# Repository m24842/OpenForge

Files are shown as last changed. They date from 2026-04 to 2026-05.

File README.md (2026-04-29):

<p align="center">
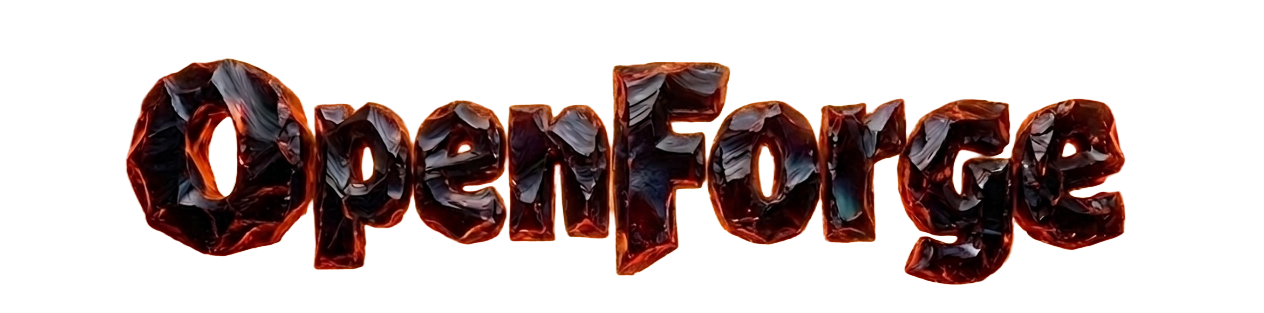
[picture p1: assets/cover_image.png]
  
</p>
<h3 align="center">GT Senior Design Project Spring 2026</h3>
<h4 align="center">
  <a href="https://coe.gatech.edu/news/2026/04/protecting-organs-water-and-military-earn-top-honors-capstone-expo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">Honorable Mention</a>
</h4>

## Overview
OpenForge is an open-source, low-cost, hobbyist-level induction furnace created to reduce the cost barrier to entry for metalworking and rapid prototyping.

<p align="center">
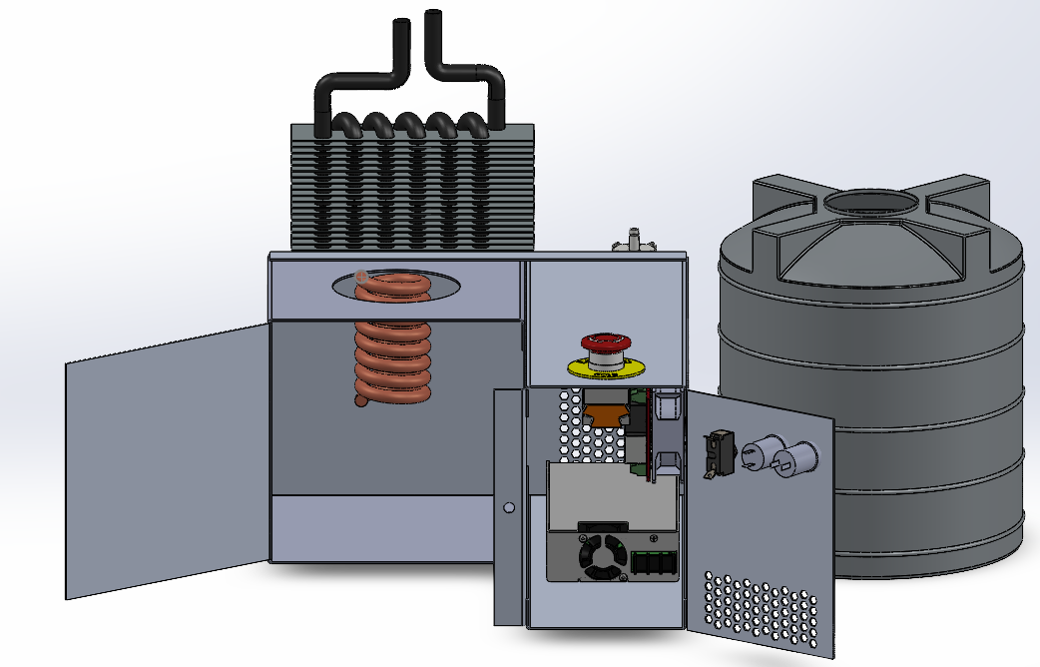
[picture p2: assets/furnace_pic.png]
  
</p>

## Documentation
### [Guides](docs/guides/README.md)
  1. [Setup](docs/guides/setup.md)
  2. [Usage](docs/guides/usage.md)
  3. [Develop](docs/guides/dev.md)
  4. [Debug](docs/guides/debug.md)

### [Reference](docs/reference/README.md)
  * [Architecture](docs/reference/arch.md)
  * [Configuration](docs/reference/configs.md)

## Demo Video
<p align="center">
  <a href="https://www.youtube.com/watch?v=rfKfzx6W2i8">
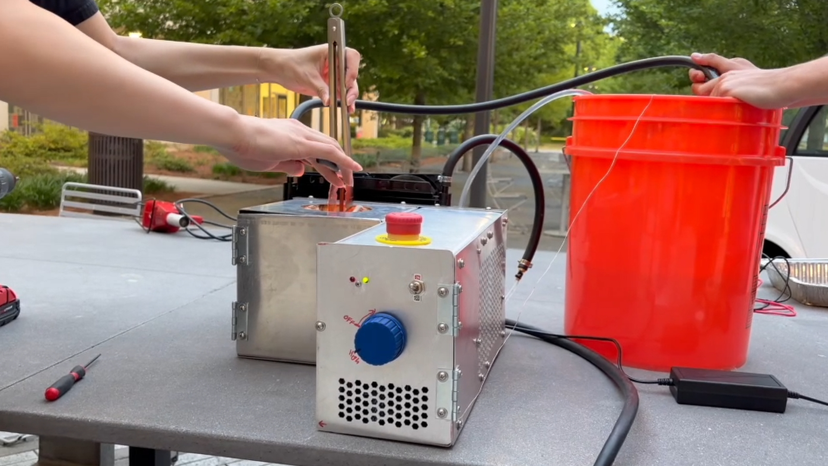
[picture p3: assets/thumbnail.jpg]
OpenForge Demo
    
  </a>
</p>

## The Team
| | Profile | Major |
| :--: | :---: | :----: |
|  | [@m24842](https://github.com/m24842) | EE |
|  | [@mollyg27](https://github.com/mollyg27) | ME |
|  | [@Dmay37](https://github.com/Dmay37) | EE |
|  | [@14joragu](https://github.com/14joragu) | EE |
|  | [@61olihar](https://github.com/61olihar) | ME |
|  | [@gchen368](https://github.gatech.edu/gchen368) | CE |

## Acknowledgments
Special thanks to __Dr. Lukas Graber__ and __Dr. Peter Hesketh__ for their guidance, insight, and support throughout this project.

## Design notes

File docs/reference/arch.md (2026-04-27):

# Architecture

## Overview

<p align="center">
  OpenForge
</p>

* [User Interface](#user-interface)
* [Heating](#heating)
* [Cooling](#cooling)
* [Control](#control)

## User Interface

### Components
|Name|Suggested Part|
|:---|---:|
|Toggle switch|[Amazon link](https://a.co/d/08M4XrNV)|
|Rotary potentiometer 10kΩ (power dial)|[Amazon link](https://a.co/d/00b6DRkQ)|
|Emergency stop button|[Amazon link](https://a.co/d/0hutAWxC)|
|120V relay|[Amazon link](https://a.co/d/00kgoHyW)|
|Red LED|-|
|Green LED|-|

### Functionality
__Inputs__:
* User input
* [Control state](#control)

__Outputs__:
* ZVS enable/disable signal
* Power dial position
* LED control signals

The furnace user interface enables intuitive control of the crucible temperature and includes three main inputs: a __power dial__, __enable/disable switch__, and __e-stop button__.

The __power dial__ outputs an analog signal [0V, 3.3V] which is converted to a current limit percentage for the ZVS power supply by the microcontroller. Since the minimum current limiting for the ZVS power supply is 10% rather than 0%, the __enable/disable switch__ allows the output to be shut off completely and enter idle mode. Both setting the current limit and output enable/disable are accomplished using CAN commands supported by the ZVS power supply (see [zvs.py](../../src/zvs.py) for further details and references).

The __e-stop button__ allows immediate termination of ZVS operation by directly controlling a relay to cut off AC power to the ZVS power supply (i.e. bypassing the microcontroller).

The furnace operation mode is displayed using __red and green LEDs__. Each LED is driven independently by the microcontroller, allowing multiple states to be displayed using flash patterns. The four furnace states include:
1. Idle: ⚫️⚫️ (both off)
    * Furnace heating is disabled
2. Ramp: ⚫️🟢 (green on)
    * Furnace is enabled and temperature is __ramping__. Ramping is identified as a changing voltage/current being drawn by the ZVS driver.
3. Steady: ⚫️🟢 (green flashing)
    * Furnace is enabled and temperature is __steady__.
    Steadiness is identified as a roughly constant voltage/current being drawn by the ZVS driver.
4. Overload: 🔴⚫️ (red flashing)
    * Furnace power supply is __overloaded__. The power supply will throttle power unless the temperature setting is reduced (throttling reduces effective power significantly). This generally only occurs when running the furnace on 240VAC.
5. Error: 🔴⚫️ (red on)
    * Furnace has entered an erroneous state. The system controller monitors temperatures of critical components and disables heating if temperature limits are exceeded.

## Heating

### Components
|Name|Suggested Part|
|:---|---:|
|ZVS driver|[Amazon link](https://a.co/d/0dc9iLwj)|
|3kW DC power supply (ZVS power supply)|*included w/ ZVS driver|
|Induction coil|*included w/ ZVS driver|
|IC temperature sensor|[Digikey link](https://www.digikey.com/short/981h0vrd)|
|Bottom pour crucible|[Amazon link](https://a.co/d/0bnduDAu) *hole must be drilled|
|Bottom pour crucible plug|[Amazon link](https://a.co/d/034yB7Kj)|
|Ceramic fiber insulation|[Amazon link](https://a.co/d/070G24vb)|
|Fiber glass coil sheath|[Amazon link](https://a.co/d/0huBojl4)|

### Functionality
__Inputs__:
* [ZVS enable/disable CAN command](#control)
* [ZVS power supply current limit](#control)

__Outputs__:
* Induction coil power
* ZVS temperature
* ZVS power supply temperature
* ZVS power supply output voltage/current

Induction heating is accomplished using a __ZVS driver__. A __3kW power supply__ feeds the __ZVS driver__ to attain temperatures required for melting common engineering metals such as aluminum. The __induction coil__ is water cooled to enable long run times and optimal heating efficiency (see [Cooling](#cooling) for further details).

The __ZVS power supply__ supports CAN commands for adjusting operation parameters such as output voltage, current, fan speed, etc. (see [zvs.py](../../src/zvs.py) for further details and references). Only two parameters are dynamically controlled during furnace operation: _current limit_ and _output enable/disable_. These are transmitted from the microcontroller to the __ZVS power supply__ based on user inputs as discussed in [User Interface](#user-interface).

Additionally, the __ZVS power supply__ supports CAN commands for reading operation parameters. The most relevant values include output voltage, current, and temperature. These are used by the microcontroller to determine furnace operation modes and error conditions as discussed in [User Interface](#user-interface).

## Cooling

### Components
|Name|Suggested Part|
|:---|---:|
|12V fans|[Amazon link](https://a.co/d/06POpfxe)|
|12V pump|*included w/ ZVS driver|
|12V relay|[Amazon link](https://a.co/d/09bBEAkq)|
|12V power supply|[Amazon link](https://a.co/d/0fyLhfdB)|
|Radiator|[Amazon link](https://a.co/d/0breF2rm)|
|Thermocouple + amplifier|[Amazon link](https://a.co/d/0a98Mzv3)|
|Tubing|[Amazon link](https://a.co/d/06ERqqzK)|
|Hose clamps|-|
|Hose adapters|-|
|Reservoir|-|

### Functionality
__Inputs__:
* [Fans on/off signal](#control)

__Outputs__:
* Coolant temperature
* Coolant flow to induction coil

Cooling critical components of the furnace is accomplished using both air and water cooling. Specifically, the induction coil is water cooled while the electronics housing is air cooled. Additionally, __fans__ are installed on the coolant radiator to maintain a reasonable water temperature for circulating through the induction coil.

The __water pump__ is always running to allow for accurate measurements of nominal water temperature using a downstream thermocouple. Water temperature measurements are transmitted to the microcontroller for determining error conditions as discussed in [User Interface](#user-interface). On the other hand, __fans__ are controlled by the microcontroller through a relay. __Fans__ only run while heating is enabled or some temperature limit has been exceeded.

## Control

### Components
|Name|Suggested Part|
|:---|---:|
|Microcontroller (MCU)|[Adafruit link](https://www.adafruit.com/product/5724)|
|CAN transceiver|*onboard the MCU|
|Buck converter|[Amazon link](https://a.co/d/0ix6y9vt)|

### Functionality
__Inputs__:
* [ZVS temperature](#heating)
* [ZVS power supply temperature](#heating)
* [ZVS power supply output voltage/current](#heating)
* [Coolant temperature](#cooling)
* [ZVS enable/disable signal](#user-interface)
* [Power dial position](#user-interface)

__Outputs__:
* Fans on/off signal
* Control state
* ZVS enable/disable CAN command
* ZVS power supply current limit

System control is split into two components: __heating control__ and __cooling control__.

__Heating control__ involves setting the ZVS power supply current limit and output disable/enable based on user inputs and component temperature readings. ZVS power supply parameters directly match user inputs as long as no temperature limits have been exceeded. If an erroneous state is encountered, heating is disabled until the furnace returns to a valid state.

__Cooling control__ involves enabling/disabling the fans for the electronics and coolant radiator. Fans are only enabled while heating is enabled or some temperature limit has been exceeded.

Additionally, the system controller is responsible for updating the furnace state displayed by the [User Interface](#user-interface).

## Miscellaneous

### Components
|Name|Suggested Part|
|:---|---:|
|Aluminum sheet|[link](https://www.onlinemetals.com/en/buy/aluminum/0-063-aluminum-sheet-5052-h32/pid/7128) *24" X 48"|
|Door hinges|-|
|Fasteners|-|

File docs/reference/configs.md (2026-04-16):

# Configuration

> __Note__: All configurations are located in [configs.py](../../src/configs.py). Default values are provided.

> __Note__: Pinouts (and other details) for the RP2040 CAN Bus Feather can be found [here](https://learn.adafruit.com/adafruit-rp2040-can-bus-feather/pinouts).

## User Interface Configurations
* `GREEN_LED_PIN`, `RED_LED_PIN`: Any two GPIO pins can be used
* `DIAL_PIN`: Any ADC capable GPIO pin can be used (i.e. GPIO 26-29)
* `SWITCH_PIN`: Any GPIO pin can be used
* `DIAL_ALPHA`: Determines the smoothing factor for translating dial position to heating power. Values closer to 1.0 reduce smoothing while values closer 0.0 increase smoothing.
* `STEADY_STATE_THRESH`: Determines the maximum deviations in output voltage and current to still be considered steady state. Makes no impact to the heating process, only status visualization.

## ZVS Driver Configurations
* `CAN_SPI`: This should not be changed from 1 since the RP2040 CAN Bus Feather has its CAN transceiver connected to SPI1
* `CAN_SPI_SCK`: Any SCK1 capable GPIO pin can be used (i.e. GPIO 10, 14, or 26)
* `CAN_SPI_MOSI`: Any TX1 capable GPIO pin can be used (i.e. GPIO 11, 15, or 27)
* `CAN_SPI_MISO`: Any RX1 capable GPIO pin can be used (i.e. GPIO 8, 12, or 28)
* `CAN_CS`: This should not be changed from GPIO 19 since CAN_CS is tied to it
* `ZVS_TEMP_PIN`: Any ADC capable GPIO pin can be used (i.e. GPIO 26-29)

## Cooling Configurations
* `COOLING_RELAY_PIN`: Any GPIO pin can be used
* `COOLING_TEMP_SPI`: This should not be changed from 0 since SPI1 is being used for CAN
* `COOLING_TEMP_SCK`: Any SCK0 capable GPIO pin can be used (i.e. GPIO 2 or 6)
* `COOLING_TEMP_MISO`: Any RX0 capable GPIO pin can be used (i.e. GPIO 0 or 4)
* `COOLING_TEMP_CS`: Any CSn0 capable GPIO pin can be used (i.e. GPIO 1 or 5)

## Control Configurations
* `MAX_ZVS_TEMP`: In celsius, determines a condition for which the system cuts power to the ZVS driver
* `MAX_ZVS_PSU_TEMP`: In celsius, determines a condition for which the system cuts power to the ZVS driver
* `MAX_COOLANT_TEMP`: In celsius, determines a condition for which the system cuts power to the ZVS driver

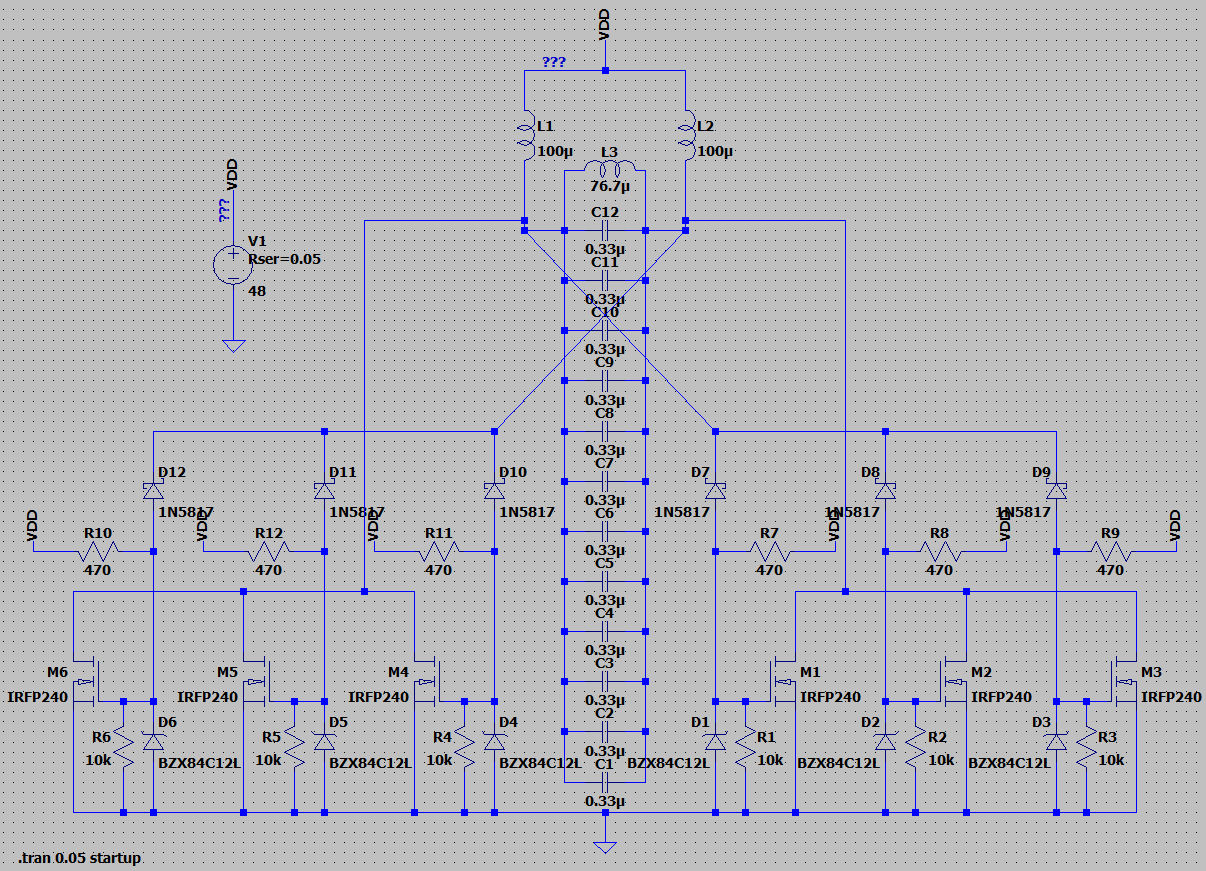
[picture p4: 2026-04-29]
pcb/ZVS_Schematic.png

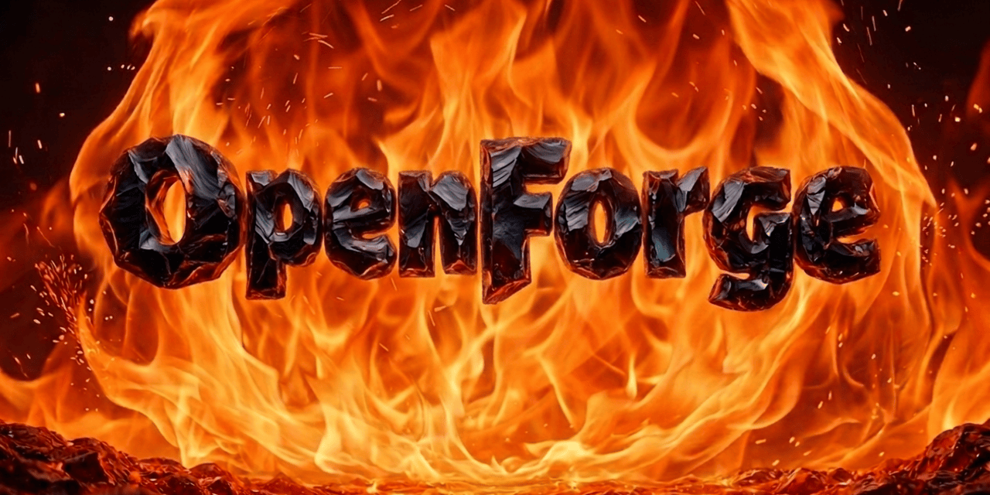
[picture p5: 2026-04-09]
assets/social_preview.png

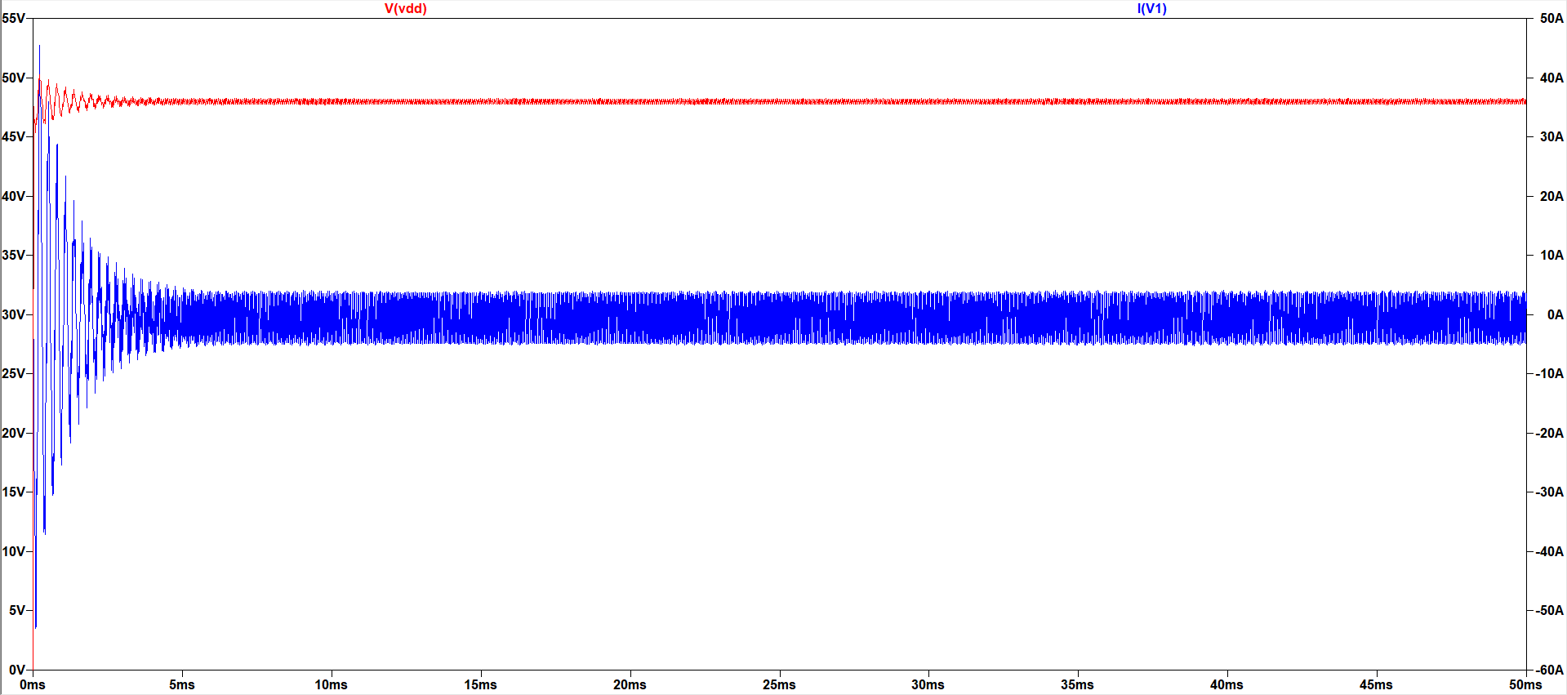
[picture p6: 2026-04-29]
pcb/ZVS_Input_V&I_Waveforms.png

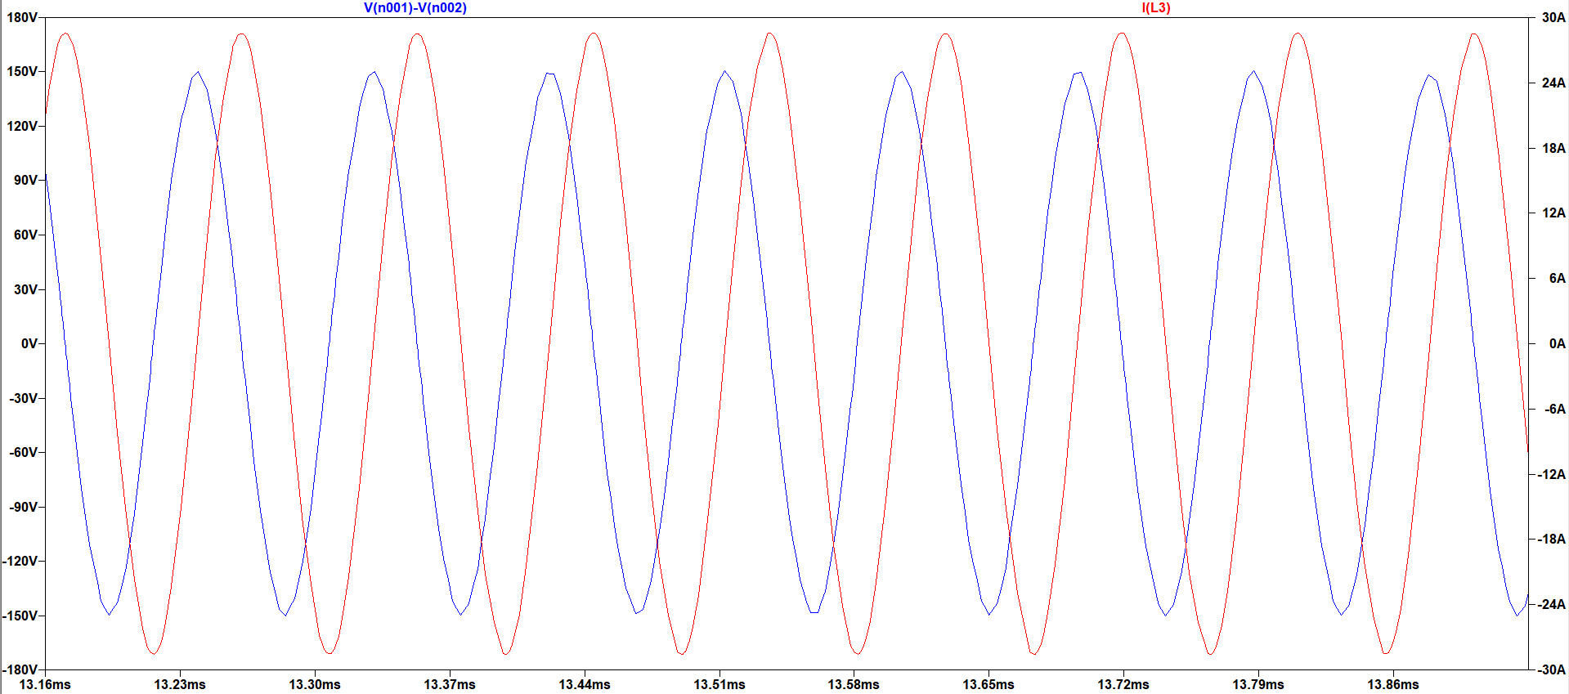
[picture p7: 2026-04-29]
pcb/ZVS_LC_Oscillation_V&I_Waveforms.png

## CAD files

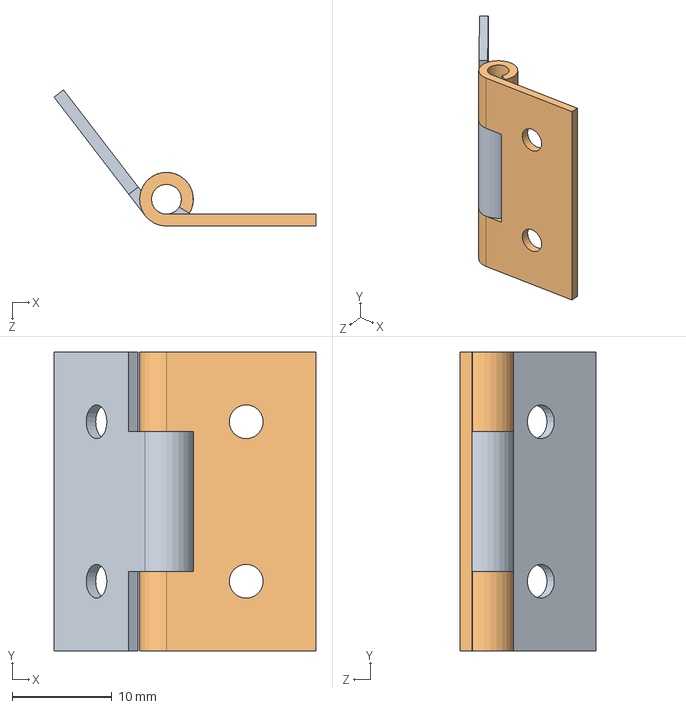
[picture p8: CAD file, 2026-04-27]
cad/PYM_303012_hinge.SLDASM
26.3 x 30.0 x 13.7 mm
PYM_303012_hinge1
PYM_303012_hinge2

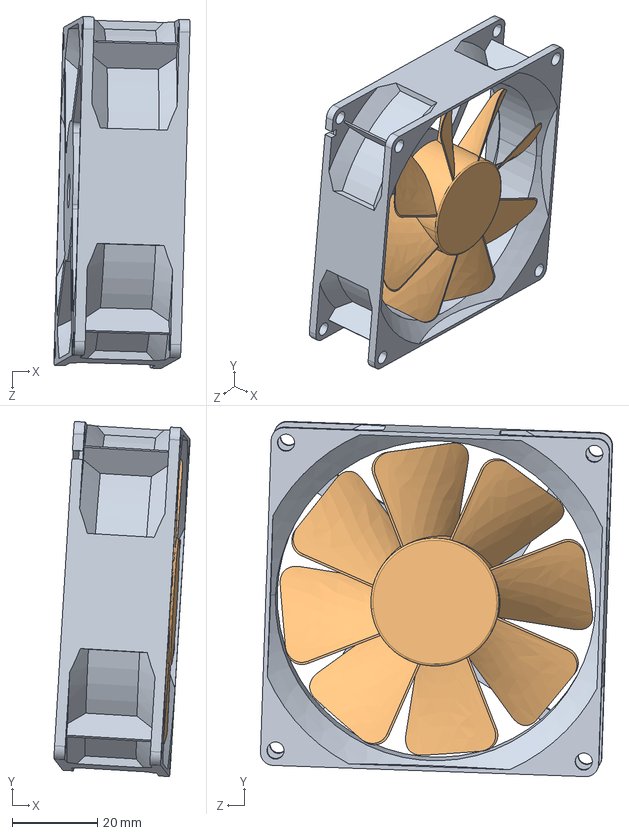
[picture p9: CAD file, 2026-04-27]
cad/Cooling Fan.STEP
31.8 x 83.1 x 82.4 mm
Fan case
Exhaust Fan Propeller

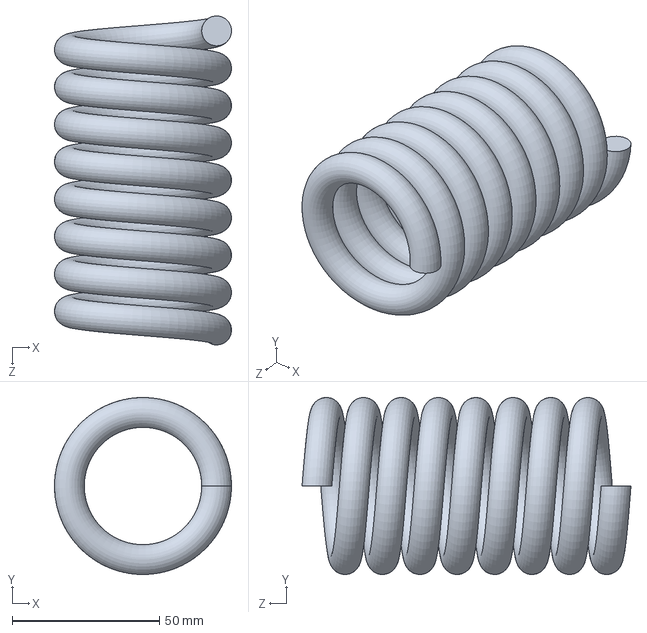
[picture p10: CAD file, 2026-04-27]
cad/coil3.SLDPRT
60.1 x 60.1 x 111.7 mm

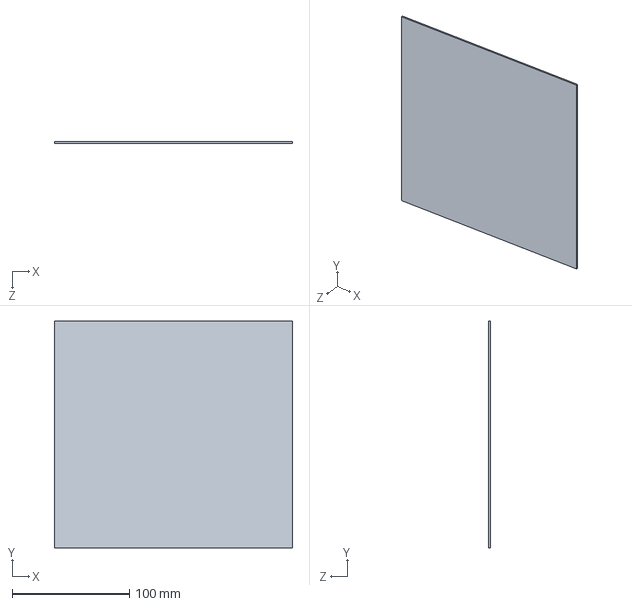
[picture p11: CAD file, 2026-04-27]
cad/door.SLDPRT
203.2 x 193.8 x 1.59 mm

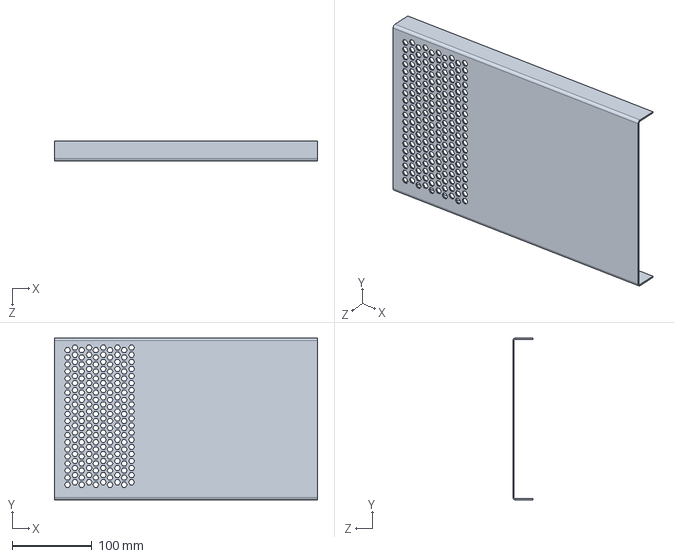
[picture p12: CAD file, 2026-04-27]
cad/back.SLDPRT
330.2 x 203.2 x 25.4 mm

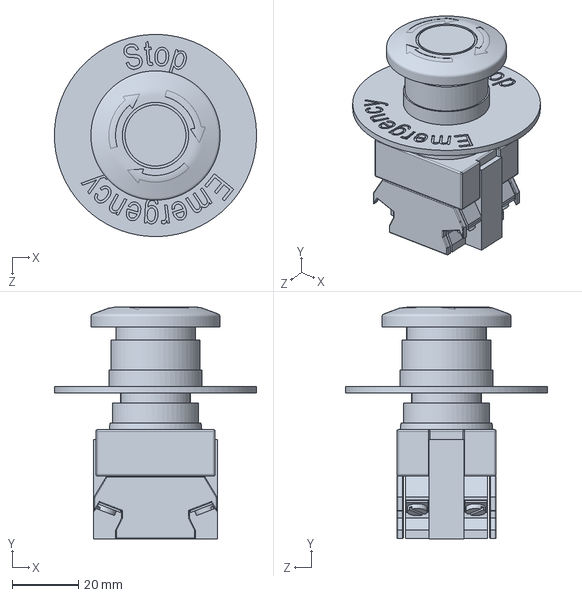
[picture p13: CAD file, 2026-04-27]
cad/Emergency Stop Button.SLDPRT
61.0 x 70.0 x 61.0 mm

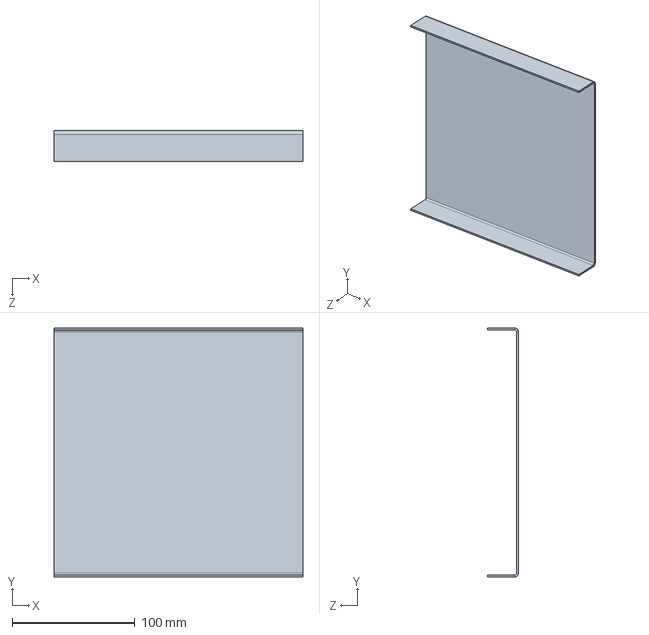
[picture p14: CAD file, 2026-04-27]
cad/bottom.SLDPRT
203.2 x 203.2 x 25.4 mm

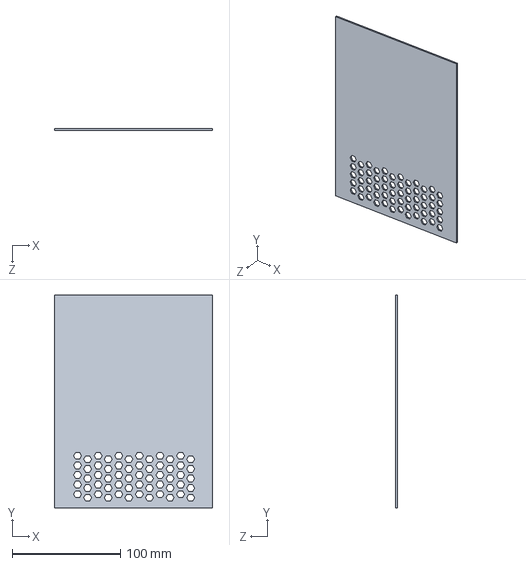
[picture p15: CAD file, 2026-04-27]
cad/controls_panel.SLDPRT
146.1 x 196.9 x 1.59 mm

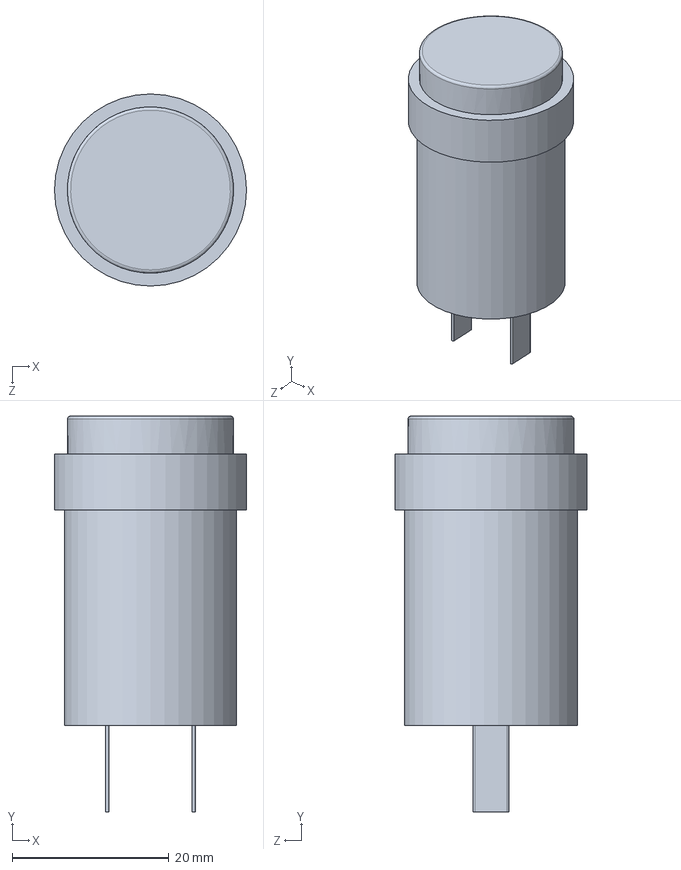
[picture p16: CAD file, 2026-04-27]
cad/LED Status -red.SLDPRT
24.5 x 50.5 x 24.5 mm

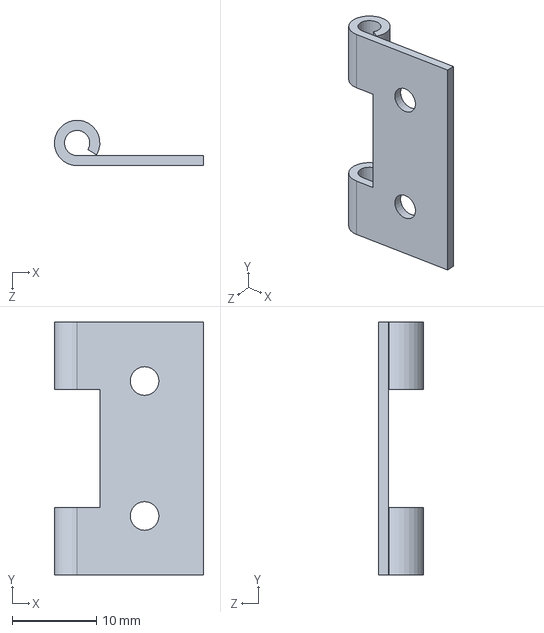
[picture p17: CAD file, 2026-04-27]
cad/PYM_303012_hinge1.SLDPRT
17.7 x 30.0 x 5.39 mm

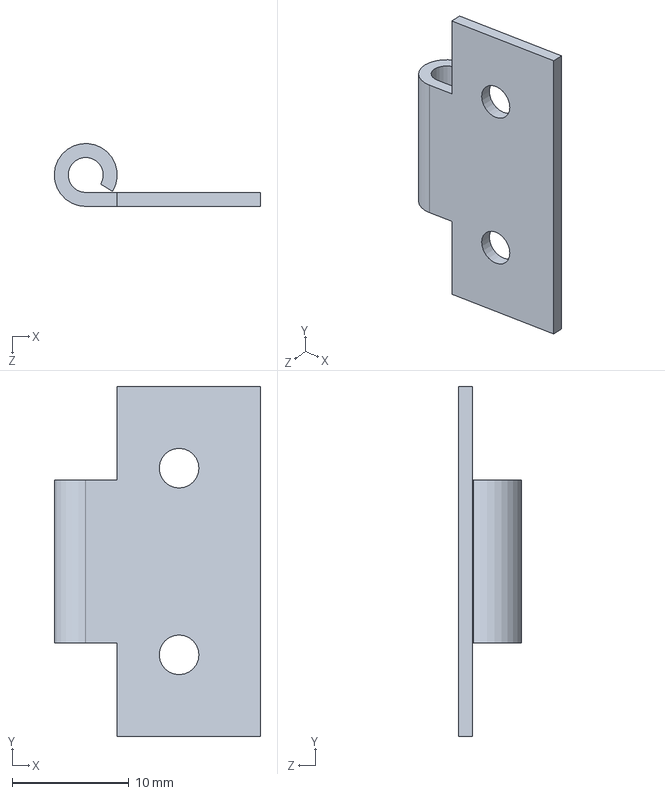
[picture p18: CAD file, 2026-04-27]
cad/PYM_303012_hinge2.SLDPRT
17.7 x 30.0 x 5.39 mm

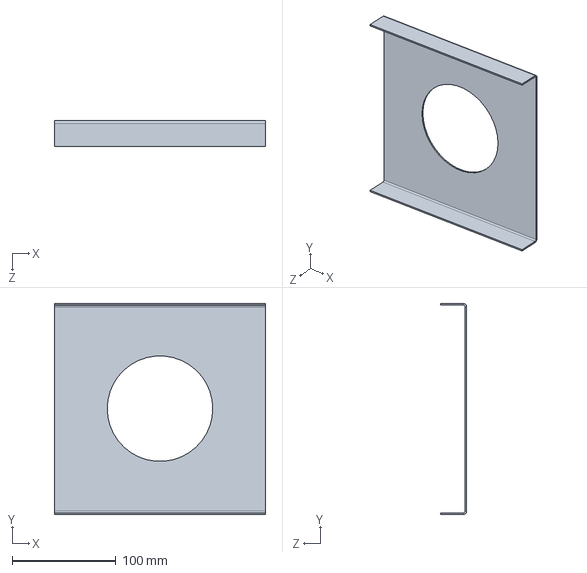
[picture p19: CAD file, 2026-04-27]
cad/Top_bottom.SLDPRT
203.2 x 203.2 x 25.4 mm

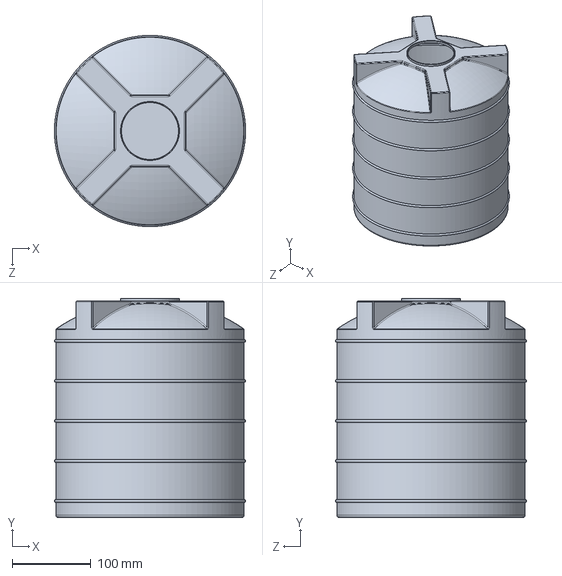
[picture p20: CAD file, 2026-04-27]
cad/Water Tank.SLDPRT
243.6 x 279.0 x 243.6 mm

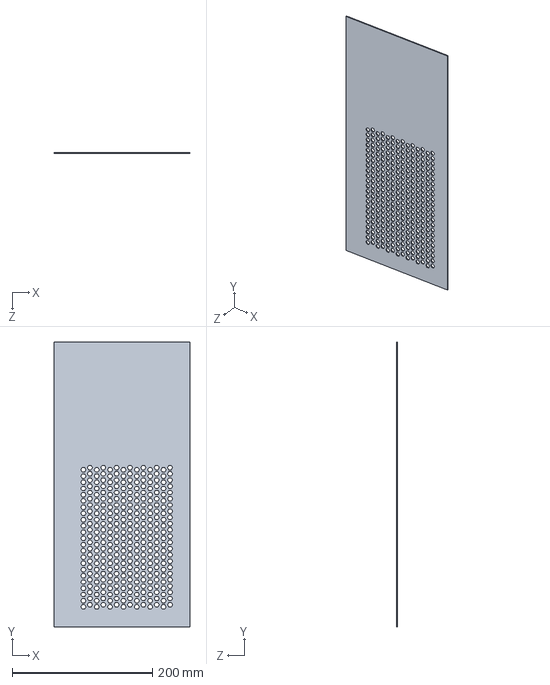
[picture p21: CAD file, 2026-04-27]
cad/side_separating_3.SLDPRT
193.7 x 406.4 x 1.59 mm

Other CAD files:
cad/12V Diaphragm Pump RS-385 - WITH BRACKETS.SLDASM
cad/LED Status -green.SLDPRT
cad/side_separating.SLDPRT
cad/Turn Knob.SLDPRT
cad/Cooling Fan.SLDASM
cad/PYM_303012_pin.SLDPRT
cad/Top_bottom_elec.SLDPRT
cad/side_separating_2.SLDPRT

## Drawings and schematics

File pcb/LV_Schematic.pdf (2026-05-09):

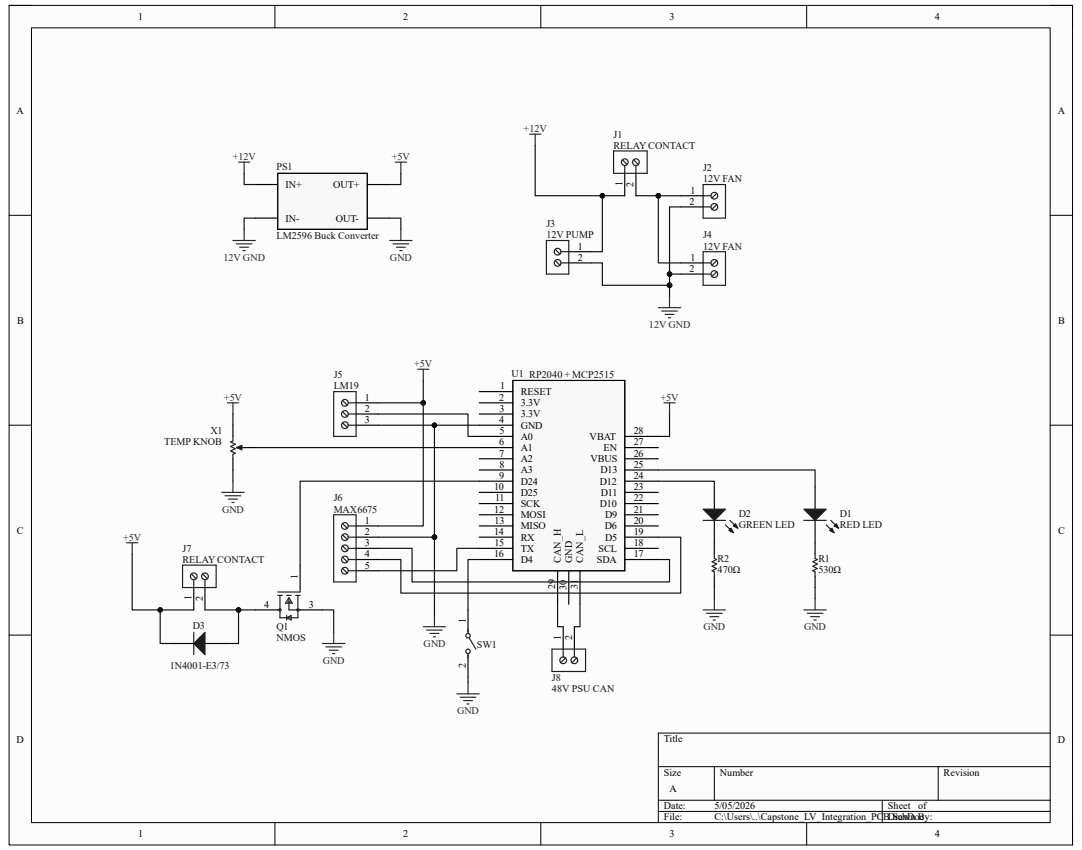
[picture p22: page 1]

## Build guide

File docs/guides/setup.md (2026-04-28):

# Setup

## Overview
1. [Software](#software)
2. [Electrical](#electrical)
3. [Hardware](#hardware)

## Software
1. Follow [this tutorial](https://randomnerdtutorials.com/raspberry-pi-pico-vs-code-micropython/) to set up MicroPython on the microcontroller and the VSCode MicroPico extension
2. Open [src](../../src) in VSCode. MicroPico should automatically recognize it as a project.
3. Run the `Upload project to Pico` command to complete setup of the microcontroller

## Electrical
1. Following the [system schematic](../../pcb), assemble the electrical hardware. This can be done using PCBs or protoboards.
2. If making modifications to GPIO usage, make sure to update [configs.py](../../src/configs.py)

## Hardware
1. Following the [design files](../../cad), fabricate and assemble components for the furnace enclosure. Feel free to modify the enclosure design to better fit your needs.
2. Mount electrical hardware to the enclosure.

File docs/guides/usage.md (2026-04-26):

# Usage

## Startup/Shutdown

### Startup Sequence
1. Disable heating using the [heating enable/disable switch](#heating-enabledisable-switch)
2. Set the [temperature dial](#temperature-dial) to the lowest setting
3. Plug in the control power supply (i.e. the PSU for the MCU and cooling)
4. Plug in the heating power supply (i.e. the PSU for the ZVS driver)
5. Reset the emergency stop button
6. Load the plugged crucible with metal
7. Situate/align the casting mold below the crucible
7. Enable heating using the [heating enable/disable switch](#heating-enabledisable-switch)
8. Set the crucible temperature using the [temperature dial](#temperature-dial)
9. Wait until furnace reaches [steady state](#furnace-operation-modes) or metal is visually molten
10. Pull the crucible plug using tongs to cast the molten metal

### Shutdown Sequence
1. Disable heating using the [heating enable/disable switch](#heating-enabledisable-switch)
2. Set the [temperature dial](#temperature-dial) to the lowest setting
3. Wait until fans shut off to ensure critical components are protected from overheating
4. Unplug in the heating power supply (i.e. the PSU for the ZVS driver)
5. Unplug in the control power supply (i.e. the PSU for the MCU and cooling)

## Temperature Control

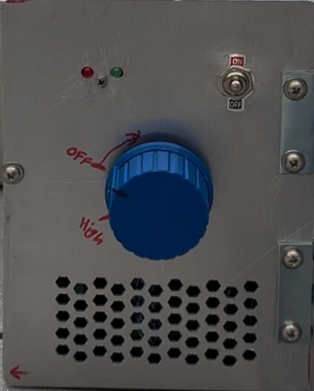
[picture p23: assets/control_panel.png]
Control Panel


### Temperature Dial:
  Crucible temperature can be adjusted down to 10% of the nominal temperature (see [Architecture](../reference/arch.md) for details). The nominal temperature of the crucible depends on the mains voltage level (i.e. 120VAC or 240VAC).

### Heating Enable/Disable Switch:
  Crucible heating can be disabled to bring the temperature down to room temperature using the heating enable/disable switch. This essentially cuts power to the induction coil as dicussed in [Architecture](../reference/arch.md).

### Furnace Operation Modes:
  The furnace operation mode is displayed using red and green LEDs (see [Architecture](../reference/arch.md) for more details). The four furnace states include:
  1. Idle: ⚫️⚫️ (both off)
      * Furnace heating is disabled
  2. Ramp: ⚫️🟢 (green on)
      * Furnace is enabled and temperature is __ramping__.
  3. Steady: ⚫️🟢 (green flashing)
      * Furnace is enabled and temperature is __steady__.
  4. Overload: 🔴⚫️ (red flashing)
      * Furnace power supply is __overloaded__ (temperature setting must be reduced).
  4. Error: 🔴⚫️ (red on)
      * Furnace has entered an erroneous state.

## Safety

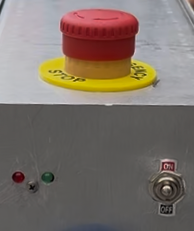
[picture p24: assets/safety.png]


### Emergency Stop Button:
  In case of an emergency, power to the induction coil can be immediately terminated by pressing the e-stop button. Cooling will continue operating to protect critical system components.

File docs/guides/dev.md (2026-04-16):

# Development

### 1. Setup Development Environment
* [MicroPython/MicroPico tutorial](https://randomnerdtutorials.com/raspberry-pi-pico-vs-code-micropython/)

### 2. Relevant Information
* [Source code](../../src)
* [Test scripts](../../tests)
* [PCB designs](../../pcb)
* [CAD models](../../cad)

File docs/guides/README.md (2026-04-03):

# Guides
1. [Setup](setup.md)
2. [Usage](usage.md)
3. [Development](dev.md)
4. [Debug](debug.md)

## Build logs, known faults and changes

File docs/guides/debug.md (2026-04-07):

# Debug

### 1. [Setup Development Environment](dev.md)
### 2. Test scripts can be found [here](../../tests)
> __Note__: Some tests can fail if abnormal environmental conditions are encountered. Sanity check logged values to determine test validity.

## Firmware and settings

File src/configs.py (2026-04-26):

######################
# ======= UI ======= #
######################
GREEN_LED_PIN = 24
RED_LED_PIN = 25
DIAL_PIN = 27
SWITCH_PIN = 4
DIAL_ALPHA = 0.1
STEADY_STATE_THRESH = 1, 1 # Volts, Amps

######################
# ====== ZVS ======= #
######################
CAN_SPI = 1 # Do NOT change
CAN_SPI_SCK = 14
CAN_SPI_MOSI = 15
CAN_SPI_MISO = 8
CAN_CS = 19 # CAN_CS -> GPIO19
ZVS_TEMP_PIN = 26

######################
# ==== Cooling ===== #
######################
COOLING_RELAY_PIN = 1
COOLING_TEMP_SPI = 0 # Do NOT change
COOLING_TEMP_SCK = 2
COOLING_TEMP_MISO = 0
COOLING_TEMP_CS = 5

######################
# ==== Control ===== #
######################
MAX_ZVS_TEMP = 60 # Celsius
MAX_ZVS_PSU_TEMP = 60 # Celsius
MAX_COOLANT_TEMP = 60 # Celsius

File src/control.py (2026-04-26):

import asyncio
from configs import *
from ui import UI
from zvs import ZVSController
from cooling import CoolingController

class SystemController:
    """
    Manages furnace operation.
    Receives inputs from the UI, monitors ZVS and coolant temps, controls the ZVS and cooling systems.
    """
    def __init__(
        self,
        max_zvs_temp: float = MAX_ZVS_TEMP,
        max_zvs_psu_temp: float = MAX_ZVS_PSU_TEMP,
        max_coolant_temp: float = MAX_COOLANT_TEMP,
    ) -> None:
        self._cooling_task = None
        self._heating_task = None
        self._max_zvs_temp = max_zvs_temp
        self._max_zvs_psu_temp = max_zvs_psu_temp
        self._max_coolant_temp = max_coolant_temp
        
        # Initialize all subsystems
        self._ui = UI()
        self._cooling = CoolingController()
        self._zvs = ZVSController()

    async def _cooling_operation(self) -> None:
        """
        Enable cooling system when ZVS is enabled or coolant temp exceeds max threshold.
        """
        while True:
            await asyncio.sleep(0.5)
            if self._zvs.enabled or self._cooling.temp > self._max_coolant_temp:
                self._cooling.enable()
            else:
                self._cooling.disable()
    
    async def _heating_operation(self) -> None:
        """
        Power ZVS based on UI inputs and ZVS status.
        """
        try:
            prev_pct = 0
            while True:
                await asyncio.sleep(0.1)
                pct = self._ui.zvs_power_level
                if pct == prev_pct: continue # Avoid redundant commands to ZVS power supply
                prev_pct = pct
                
                if self._ui.enable_zvs:
                    if self._zvs.overload: self._ui.set_status(UI.OVERLOAD)
                    elif self._zvs.steady: self._ui.set_status(UI.STEADY)
                    else: self._ui.set_status(UI.RAMP)
                    self._zvs.enable()
                    self._zvs.set_current_limit(pct)
                else:
                    self._ui.set_status(UI.IDLE)
                    self._zvs.disable()
        except asyncio.CancelledError:
            # Shutdown procedure
            self._zvs.disable()
            self._ui.set_status(UI.ERROR)
    
    async def _monitored_operation(self) -> None:
        """
        Run furnace operations while monitoring temps to trigger safe shutdown if thresholds are exceeded.
        """
        await self._zvs.start_update() # Start ZVS state updates
        self._cooling_task = asyncio.create_task(self._cooling_operation()) # Manage cooling system
        self._heating_task = asyncio.create_task(self._heating_operation()) # Manage ZVS power
        while True:
            await asyncio.sleep(0.5)
            stop = any([
                self._zvs.temp > self._max_zvs_temp, # ZVS over-temp
                self._zvs.supply_temp > self._max_zvs_psu_temp, # ZVS supply over-temp
                self._cooling.temp > self._max_coolant_temp, # Coolant over-temp
            ])
            if stop and not self._heating_task.done():
                # Shutdown ZVS
                self._heating_task.cancel()
                try: await self._heating_task
                except asyncio.CancelledError: pass
            elif not stop:
                if not self._heating_task.done(): continue
                exc = self._heating_task.exception()
                if exc: print("Heating task err:", exc)
                self._heating_task = asyncio.create_task(self._heating_operation()) # Restart ZVS operation
    
    async def run(self) -> None:
        asyncio.create_task(self._monitored_operation())
        while True: await asyncio.sleep(60)

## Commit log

2026-04-03 temperature sensing implementation
2026-04-04 temperature sensor integration
2026-04-22 add cad placeholder
2026-04-22 add pcb placeholder
2026-04-23 add power supply overload indication
2026-04-26 change switch state to polling
2026-05-09 add lv schematic
    [LV_PCB.PrjPcb, LV_PCB.SchDoc]
